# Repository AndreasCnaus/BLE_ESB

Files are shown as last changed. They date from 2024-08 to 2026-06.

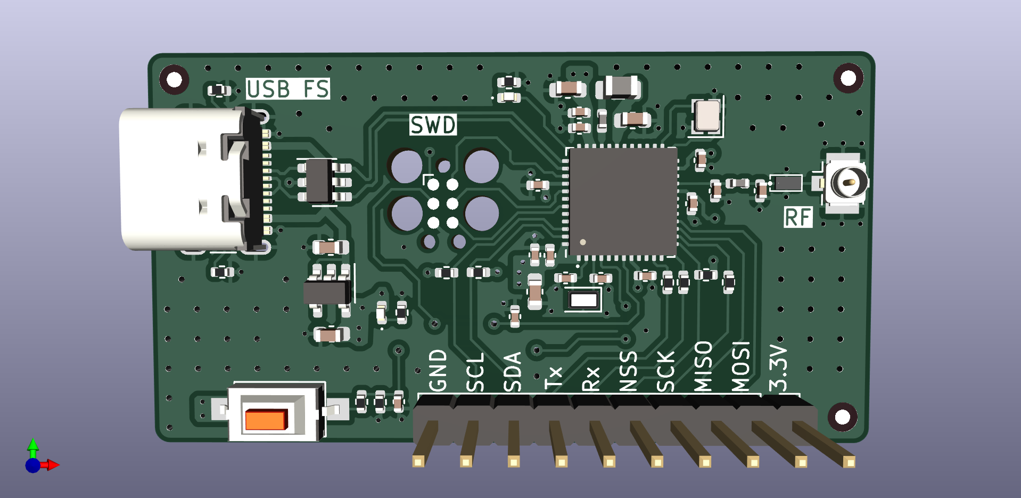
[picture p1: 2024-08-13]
hardware/docs/BluetoothPill.png

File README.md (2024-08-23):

# Hardware Setup
- Bluetooth Breakout Board (see also Hardware Section)
- Bosch BME280 Sensor
- RF-Antenna

BLE_ESB_Prototyp

# Verification with nRF-Connect
ble_es_data

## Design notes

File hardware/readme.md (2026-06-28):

# Bluetooth Breakout Board

USB Powered STM32WB55 based breakout board for wireless applications within 2.4GHz ISM-Band (e.g BLE). 

BluetoothPill

# Characteristics
Input Voltage-Range: &nbsp; 3.4V - 5.5V <br>
Output Voltage: &nbsp; 3.3V <br>
Crystals: &nbsp; HSE: 32MHz, LSE: 32.768kHz <br> 
MCU: &nbsp; STM32WB55CEU6 <br>
SMPS-Support: &nbsp;  for low power mode <br>
BOOT0/User-Button: &nbsp; boots from USB when pushed during power up <br>
LED's:  &nbsp; Power-Led (orange), User-Led (blue) <br>
Serial Wire Debug with Tag-Connec <br>

## Connectivity
USB-FS with 12Mb/s <br>
I2C1: &nbsp; (SDA, SCL) <br>
UART1: &nbsp; (Tx, Rx) <br>
SPI1: &nbsp; (NSS, SCK, MISO, MOSI) <br>
RF: &nbsp; 2.4GHz ISM-Band, BLE 5.4, IEEE 802.15.4 (Zigbee 3.0, Thread 1.3) <br>

# Links
STM32WB55-Datasheet: &nbsp; https://www.st.com/resource/en/datasheet/stm32wb55cc.pdf <br>

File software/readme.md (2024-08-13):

pinout_view

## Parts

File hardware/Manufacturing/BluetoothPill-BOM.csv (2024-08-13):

Designator | Quantity | Value | Footprint | Description | Manufacturer | Manufacturer Part Number | Distributor Link
C1, C2, C5, C8, C16 | 5 | 4u7 | Capacitor_SMD:C_0603_1608Metric | Unpolarized capacitor | KYOCERA AVX | KGM15CR51E475KT | https://www.mouser.de/ProductDetail/KYOCERA-AVX/KGM15CR51E475KT?qs=Jm2GQyTW%2FbixQyNI34FoPQ%3D%3D
C3, C4, C6, C7, C9, C10, C11, C12, C15, C17 | 10 | 100n | Capacitor_SMD:C_0402_1005Metric | Unpolarized capacitor | Wurth Elektronik | 885012205086 | https://www.mouser.de/ProductDetail/Wurth-Elektronik/885012205086?qs=amGC7iS6iy9PDKAAMqQhzg%3D%3D
C13, C14 | 2 | 10p | Capacitor_SMD:C_0402_1005Metric | Unpolarized capacitor | KEMET | C0402C100K8HACAUTO | https://www.mouser.de/ProductDetail/KEMET/C0402C100K8HACAUTO?qs=j%252B1pi9TdxUbSCidW22i%2FeQ%3D%3D
C18 | 1 | 0p8 | Capacitor_SMD:C_0402_1005Metric | Unpolarized capacitor | Murata Electronics | GRM1555C1HR80BA01D | https://www.mouser.de/ProductDetail/Murata-Electronics/GRM1555C1HR80BA01D?qs=e%252BE4OD6MgMezPYPintwvrA%3D%3D
C19 | 1 | 0p3 | Capacitor_SMD:C_0402_1005Metric | Unpolarized capacitor | Murata Electronics | GRM1555C1HR30WA01D | https://www.mouser.de/ProductDetail/Murata-Electronics/GRM1555C1HR30WA01D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
D1 | 1 | Green | LED_SMD:LED_0402_1005Metric | Light emitting diode | Lite-On | LTST-C281KGKT | https://www.mouser.de/ProductDetail/Lite-On/LTST-C281KGKT?qs=xb8aMrBSZRJ6%2FVAKgwiAkw%3D%3D
D2 | 1 | Blue | LED_SMD:LED_0402_1005Metric | Light emitting diode | Vishay Semiconductors | VLMB1500-GS08 | https://www.mouser.de/ProductDetail/Vishay-Semiconductors/VLMB1500-GS08?qs=2BArZ0I3Qlk9hauZMM5azA%3D%3D
FTL1 | 1 | DLF162500LT-5028A1 | custom:DLF162500LT-5028A1 | RF-Lowpass filter | TDK | DLF162500LT-5028A1 | https://www.mouser.de/ProductDetail/TDK/DLF162500LT-5028A1?qs=U%2FZX79kHR%2FlwIbAISCs3qA%3D%3D
J1 | 1 | USB_C_Receptacle_USB2.0 | Connector_USB:USB_C_Receptacle_GCT_USB4105-xx-A_16P_TopMnt_Horizontal | USB 2.0-only Type-C Receptacle connector | GCT | USB4105-GF-A | https://www.mouser.de/ProductDetail/GCT/USB4105-GF-A?qs=KUoIvG%2F9IlY%2FMLlBMpStpA%3D%3D
J4 | 1 | Conn_Coaxial | Connector_Coaxial:U.FL_Hirose_U.FL-R-SMT-1_Vertical | coaxial connector (BNC, SMA, SMB, SMC, Cinch/RCA, LEMO, ...) | Hirose Connector | U.FL-R-SMT(01) | https://www.mouser.de/ProductDetail/Hirose-Connector/U.FL-R-SMT01?qs=Ux3WWAnHpjDV3tCCbDi65g%3D%3D
L1 | 1 | 10n | Inductor_SMD:L_0402_1005Metric | Inductor | Murata Electronics | LQG15WZ10NJ02D | https://www.mouser.de/ProductDetail/Murata-Electronics/LQG15WZ10NJ02D?qs=60uY6ySkanT1eJ7IaeAl%2Fg%3D%3D
L2 | 1 | 10u | Inductor_SMD:L_0805_2012Metric | Inductor | Murata Electronics | LQM21FN100M70L | https://www.mouser.de/ProductDetail/Murata-Electronics/LQM21FN100M70L?qs=8M15sSGRUn%252BogwBrvQUwLA%3D%3D
L3 | 1 | 2n7 | Inductor_SMD:L_0402_1005Metric | Inductor | Murata Electronics | LQG15HS2N7S02D | https://www.mouser.de/ProductDetail/Murata-Electronics/LQG15HS2N7S02D?qs=ctz47l0uL1AKrLI74yO5Qw%3D%3D
R1, R2, R3, R6, R7, R12 | 6 | 220R | Resistor_SMD:R_0402_1005Metric | Resistor | YAGEO | AF0402JR-07220RL | https://www.mouser.de/ProductDetail/YAGEO/AF0402JR-07220RL?qs=Ghq3E7L6HNfV8BjGdjwaqw%3D%3D
R4, R5, R8, R9, R10, R11 | 6 | 5k1 | Resistor_SMD:R_0402_1005Metric | Resistor | Panasonic | ERJ-2RKF5101X | https://www.mouser.de/ProductDetail/Panasonic/ERJ-2RKF5101X?qs=YMBIwoNQYdXx9lAucePQAA%3D%3D
SW1 | 1 | SW_Push | Button_Switch_SMD:SW_SPST_CK_RS282G05A3 | Push button switch, generic, two pins | C&K | RS282G05A3SMRT | https://www.mouser.de/ProductDetail/CK/RS282G05A3SMRT?qs=Gufeu08L%2Fl2VU43xmeLp5Q%3D%3D
U1 | 1 | MIC5365-3.3YD5 | Package_TO_SOT_SMD:SOT-23-5 | 150mA Low-dropout Voltage Regulator, Vout 3.3V, Vin up to 5.5V, SOT-23-5 | Microchip Technology | MIC5365-3.3YD5-TR | https://www.mouser.de/ProductDetail/Microchip-Technology/MIC5365-3.3YD5-TR?qs=U6T8BxXiZAXzRinbbfZRrg%3D%3D
U2 | 1 | USBLC6-2SC6 | Package_TO_SOT_SMD:SOT-23-6 | Very low capacitance ESD protection diode, 2 data-line, SOT-23-6 | STMicroelectronics | USBLC6-2SC6 | https://www.mouser.de/ProductDetail/STMicroelectronics/USBLC6-2SC6?qs=po45yt2pPpu%2FhNIlwQdTlg%3D%3D
U3 | 1 | STM32WB55CEU6 | Package_DFN_QFN:QFN-48-1EP_7x7mm_P0.5mm_EP5.6x5.6mm | STMicroelectronics Arm Cortex-M4 MCU, 512KB flash, 256KB RAM, 64 MHz, 1.71-3.6V, 30 GPIO, UFQFPN48 | STMicroelectronics | STM32WB55CEU6 | https://www.mouser.de/ProductDetail/STMicroelectronics/STM32WB55CEU6
X1 | 1 | 32k768 | Crystal:Crystal_SMD_2012-2Pin_2.0x1.2mm | Two pin crystal | NDK | NX2012SA-32.768K-STD-MUB-1 | https://www.mouser.de/ProductDetail/NDK/NX2012SA-32.768K-STD-MUB-1?qs=55YtniHzbhA%252B6%2Fl1MwFZaQ%3D%3D
X2 | 1 | 32M | Crystal:Crystal_SMD_2016-4Pin_2.0x1.6mm | Four pin crystal, GND on pins 2 and 4 | NDK | NX2016SA-32M-EXS00A-CS06465 | https://www.mouser.de/ProductDetail/NDK/NX2016SA-32M-EXS00A-CS06465?qs=w%2Fv1CP2dgqr82b0JjRnv4A%3D%3D

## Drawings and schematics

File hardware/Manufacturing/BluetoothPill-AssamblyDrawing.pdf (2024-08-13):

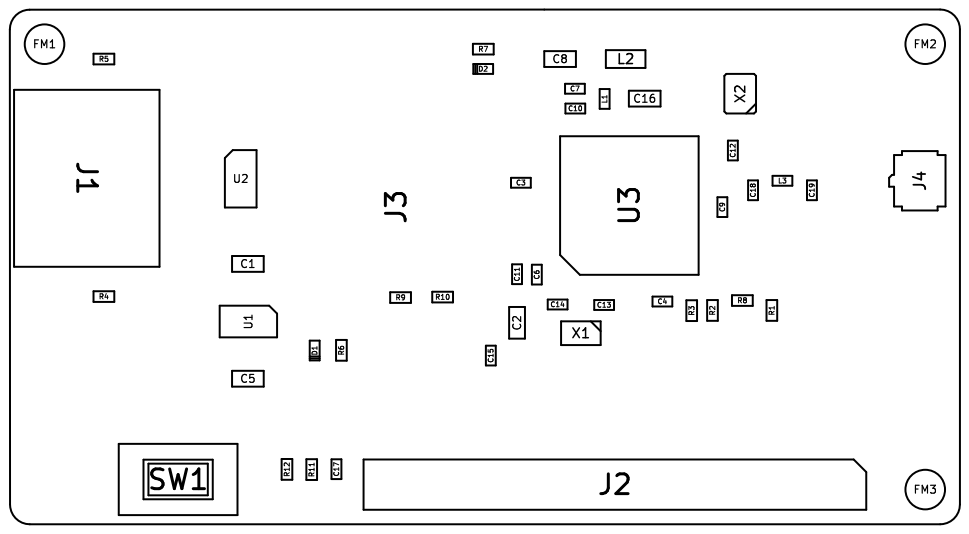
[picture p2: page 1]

Id: 1/1 Title: File: BluetoothPill.kicad_pcb Sheet:

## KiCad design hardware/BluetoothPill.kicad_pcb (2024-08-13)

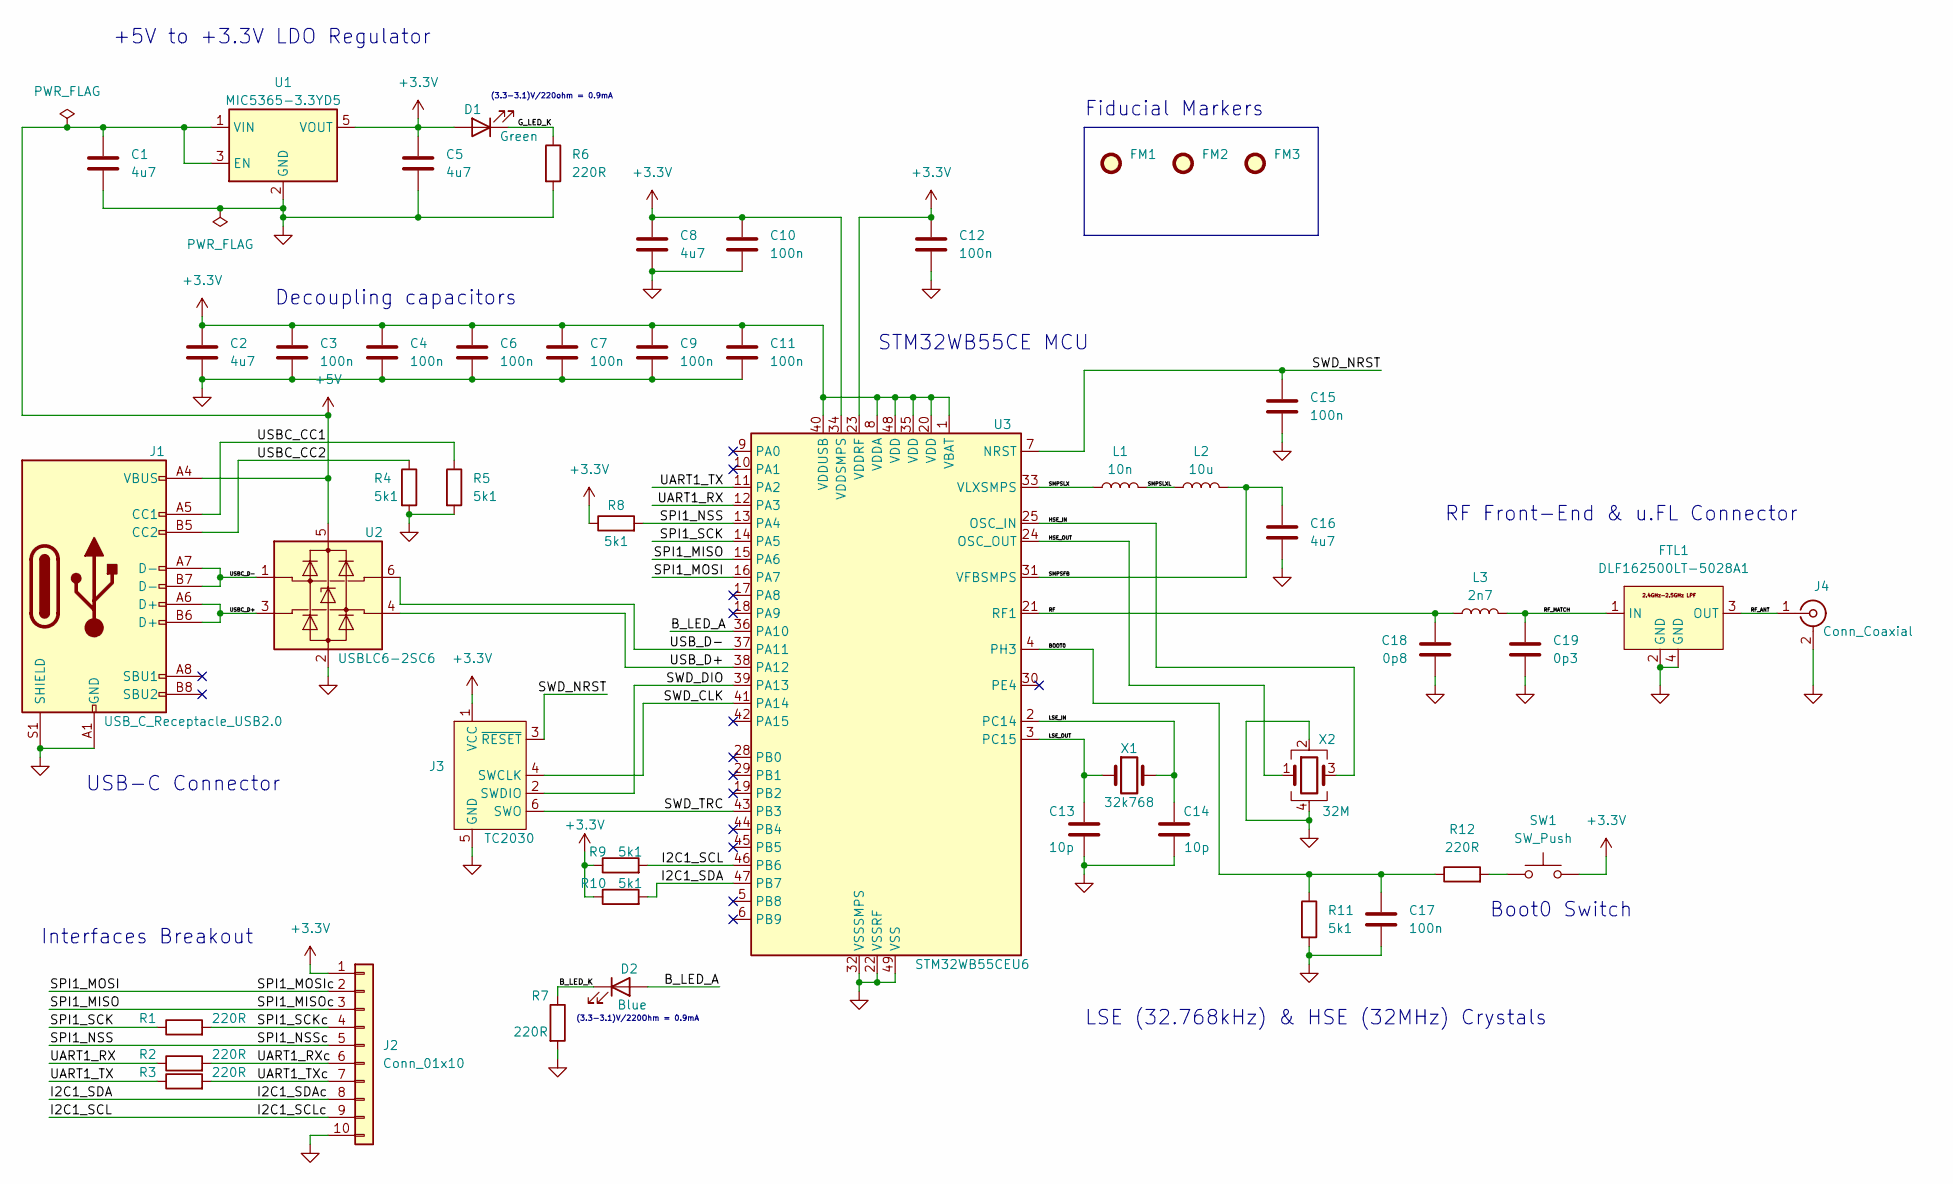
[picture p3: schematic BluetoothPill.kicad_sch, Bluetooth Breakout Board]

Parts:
C1, C2, C5, C8, C16: 4u7; C_0603_1608Metric; Manufacturer Part Numb KGM15CR51E475KT
C3, C4, C6, C7, C9, C10, C11, C12, C15, C17: 100n; C_0402_1005Metric; Manufacturer Part Numb 885012205086
C13, C14: 10p; C_0402_1005Metric; Manufacturer Part Numb C0402C100K8HACAUTO
C18: 0p8; C_0402_1005Metric; Manufacturer Part Numb GRM1555C1HR80BA01D
C19: 0p3; C_0402_1005Metric; Manufacturer Part Numb GRM1555C1HR30WA01D
D1: Green; LED_0402_1005Metric; Manufacturer Part Numb LTST-C281KGKT
D2: Blue; LED_0402_1005Metric; Manufacturer Part Numb VLMB1500-GS08
FM1, FM2, FM3: Fiducial; Fiducial_1mm_Mask2mm
FTL1: DLF162500LT-5028A1; Manufacturer Part Numb DLF162500LT-5028A1
J1: USB_C_Receptacle_USB2.0; USB_C_Receptacle_GCT_USB4105-xx-A_16P_TopMnt_Horizontal; Manufacturer Part Numb USB4105-GF-A
J2: Conn_01x10; PinHeader_1x10_P2.54mm_Vertical
J3: TC2030; Tag-Connect_TC2030-IDC-FP_2x03_P1.27mm_Vertical
J4: Conn_Coaxial; U.FL_Hirose_U.FL-R-SMT-1_Vertical; Manufacturer Part Numb U.FL-R-SMT(01)
L1: 10n; L_0402_1005Metric; Manufacturer Part Numb LQG15WZ10NJ02D
L2: 10u; L_0805_2012Metric; Manufacturer Part Numb LQM21FN100M70L
L3: 2n7; L_0402_1005Metric; Manufacturer Part Numb LQG15HS2N7S02D
R1, R2, R3, R6, R7, R12: 220R; R_0402_1005Metric; Manufacturer Part Numb AF0402JR-07220RL
R4, R5, R8, R9, R10, R11: 5k1; R_0402_1005Metric; Manufacturer Part Numb ERJ-2RKF5101X
SW1: SW_Push; SW_SPST_CK_RS282G05A3; Manufacturer Part Numb RS282G05A3SMRT
U1: MIC5365-3.3YD5; SOT-23-5; Manufacturer Part Numb MIC5365-3.3YD5-TR
U2: USBLC6-2SC6; SOT-23-6; Manufacturer Part Numb USBLC6-2SC6
U3: STM32WB55CEU6; QFN-48-1EP_7x7mm_P0.5mm_EP5.6x5.6mm; Manufacturer Part Numb STM32WB55CEU6
X1: 32k768; Crystal_SMD_2012-2Pin_2.0x1.2mm; Manufacturer Part Numb NX2012SA-32.768K-STD-MUB-1
X2: 32M; Crystal_SMD_2016-4Pin_2.0x1.6mm; Manufacturer Part Numb NX2016SA-32M-EXS00A-CS06465

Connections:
+3.3V: C2.1, C3.1, C4.1, C5.1, C6.1, C7.1, C8.1, C9.1, C10.1, C11.1, C12.1, D1.2 (A), J2.1, J3.1 (VCC), R8.1, R9.1, R10.1, SW1.2, U1.5 (VOUT), U3.1 (VBAT), U3.8 (VDDA), U3.20 (VDD), U3.23 (VDDRF), U3.34 (VDDSMPS), U3.35 (VDD), U3.40 (VDDUSB), U3.48 (VDD)
+5V: C1.1, J1.A4 (VBUS), J1.A9 (VBUS), J1.B4 (VBUS), J1.B9 (VBUS), U1.1 (VIN), U1.3 (EN), U2.5 (VBUS)
/BOOT0: C17.1, R11.1, R12.1, U3.4 (PH3)
/B_LED_A: D2.2 (A), U3.36 (PA10)
/B_LED_K: D2.1 (K), R7.1
/G_LED_K: D1.1 (K), R6.1
/HSE_IN: U3.25 (OSC_IN), X2.3
/HSE_OUT: U3.24 (OSC_OUT), X2.1
/I2C1_SCL: J2.9, R9.2, U3.46 (PB6)
/I2C1_SDA: J2.8, R10.2, U3.47 (PB7)
/LSE_IN: C14.1, U3.2 (PC14), X1.2
/LSE_OUT: C13.1, U3.3 (PC15), X1.1
/RF: C18.1, L3.1, U3.21 (RF1)
/RF_ANT: FTL1.3 (OUT), J4.1 (In)
/RF_MATCH: C19.1, FTL1.1 (IN), L3.2
/SMPSFB: C16.1, L2.2, U3.31 (VFBSMPS)
/SMPSLX: L1.1, U3.33 (VLXSMPS)
/SMPSLXL: L1.2, L2.1
/SPI1_MISO: J2.3, U3.15 (PA6)
/SPI1_MOSI: J2.2, U3.16 (PA7)
/SPI1_NSS: J2.5, R8.2, U3.13 (PA4)
/SPI1_SCK: R1.1, U3.14 (PA5)
/SPI1_SCKc: J2.4, R1.2
/SWD_CLK: J3.4 (SWCLK), U3.41 (PA14)
/SWD_DIO: J3.2 (SWDIO), U3.39 (PA13)
/SWD_NRST: C15.1, J3.3 (~RESET), U3.7 (NRST)
/SWD_TRC: J3.6 (SWO), U3.43 (PB3)
/UART1_RX: R2.1, U3.12 (PA3)
/UART1_RXc: J2.6, R2.2
/UART1_TX: R3.1, U3.11 (PA2)
/UART1_TXc: J2.7, R3.2
/USBC_CC1: J1.A5 (CC1), R5.1
/USBC_CC2: J1.B5 (CC2), R4.1
/USBC_D+: J1.A6 (D+), J1.B6 (D+), U2.3 (I/O1)
/USBC_D-: J1.A7 (D-), J1.B7 (D-), U2.1 (I/O1)
/USB_D+: U2.4 (I/O2), U3.38 (PA12)
/USB_D-: U2.6 (I/O2), U3.37 (PA11)
GND: C1.2, C2.2, C3.2, C4.2, C5.2, C6.2, C7.2, C8.2, C9.2, C10.2, C11.2, C12.2, C13.2, C14.2, C15.2, C16.2, C17.2, C18.2, C19.2, FTL1.2 (GND), FTL1.4 (GND), J1.A1 (GND), J1.A12 (GND), J1.B1 (GND), J1.B12 (GND), J1.S1 (SHIELD), J2.10, J3.5 (GND), J4.2 (Ext), R4.2, R5.2, R6.2, R7.2, R11.2, U1.2 (GND), U2.2 (GND), U3.22 (VSSRF), U3.32 (VSSSMPS), U3.49 (VSS), X2.2, X2.4
unnamed: R12.2, SW1.1

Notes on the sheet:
Fiducial Markers
USB-C Connector
RF Front-End & u.FL Connector
+5V to +3.3V LDO Regulator
(3.3-3.1)V/220Ohm = 0.9mA
LSE (32.768kHz) & HSE (32MHz) Crystals
Interfaces Breakout
Decoupling capacitors
Boot0 Switch
(3.3-3.1)V/220ohm = 0.9mA
STM32WB55CE MCU

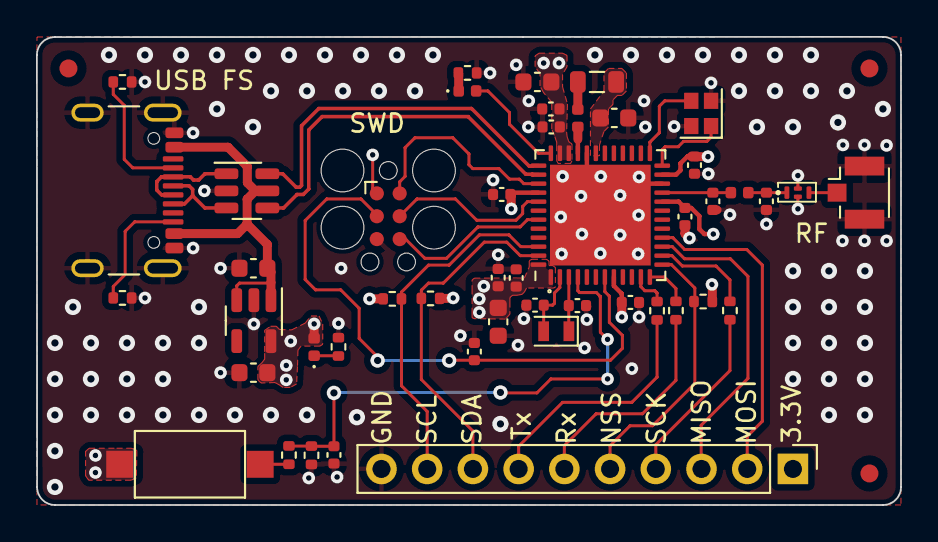
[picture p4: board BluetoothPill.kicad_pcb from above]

Board: 4 copper layers, 48.0 x 26.0 mm, 50 parts (0 on the bottom side), 39 nets.

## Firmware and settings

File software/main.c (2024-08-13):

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
/* Includes ------------------------------------------------------------------*/
#include "main.h"
#include "usb_device.h"

/* USER CODE BEGIN Includes */
#include <stdio.h>

#include "usbd_cdc_if.h"
#include "common_blesvc.h"
#include "custom_stm.h"
#include "BME280.h"
#include <stdlib.h>

/* USER CODE END Includes */

/* USER CODE BEGIN PTD */
uint8_t tim16_flag = 0;

/* USER CODE END PTD */

I2C_HandleTypeDef hi2c1;

IPCC_HandleTypeDef hipcc;

RTC_HandleTypeDef hrtc;

TIM_HandleTypeDef htim16;

/* USER CODE BEGIN PV */
BME280 bme280;
uint8_t tim16_cnt = 0;

/* USER CODE END PV */

void SystemClock_Config(void);
void PeriphCommonClock_Config(void);
static void MX_GPIO_Init(void);
static void MX_IPCC_Init(void);
static void MX_RTC_Init(void);
static void MX_TIM16_Init(void);
static void MX_I2C1_Init(void);
static void MX_RF_Init(void);
/**
  * @brief  The application entry point.
  * @retval int
  */
int main(void)
{

  /* MCU Configuration--------------------------------------------------------*/

  /* Reset of all peripherals, Initializes the Flash interface and the Systick. */
  HAL_Init();
  /* Config code for STM32_WPAN (HSE Tuning must be done before system clock configuration) */
  MX_APPE_Config();

  /* Configure the system clock */
  SystemClock_Config();

  /* Configure the peripherals common clocks */
  PeriphCommonClock_Config();

  /* IPCC initialisation */
  MX_IPCC_Init();

  /* Initialize all configured peripherals */
  MX_GPIO_Init();
  MX_RTC_Init();
  MX_TIM16_Init();
  MX_I2C1_Init();
  MX_USB_Device_Init();
  MX_RF_Init();
  /* USER CODE BEGIN 2 */
  BME280_cmd_res cmd_res = BME280_init(&bme280, &hi2c1);
  if (cmd_res != BME280_CMD_OK) {
	  HAL_GPIO_WritePin(GPIOA, GPIO_PIN_10, GPIO_PIN_SET);	// indicate error with LED on PA10
  }

  /* USER CODE END 2 */

  /* Init code for STM32_WPAN */
  MX_APPE_Init();

  /* Infinite loop */
  /* USER CODE BEGIN WHILE */
  HAL_TIM_Base_Start_IT(&htim16);

  while (1)
  {
	  if (tim16_flag){

		  BME280_cmd_res cmd_res = BME280_read_env_data(&bme280);
		  if (cmd_res != BME280_CMD_OK) {
			  HAL_GPIO_WritePin(GPIOA, GPIO_PIN_10, GPIO_PIN_SET);	// indicate error with LED on PA10
		  }

		  // convert measurement data to the appropriate units for nRF-Connect Application
		  BME280_U32_t hum_prh = (float)bme280.H/kH * 100.0;	// relative humidity in Percent
		  BME280_U32_t pres_pa=  bme280.P/kP;	//in Pascal

		  Custom_STM_App_Update_Char(CUSTOM_STM_TEMPERATURE, (uint8_t *)&bme280.T);
		  Custom_STM_App_Update_Char(CUSTOM_STM_HUMIDITY, (uint8_t *)&hum_prh);
		  Custom_STM_App_Update_Char(CUSTOM_STM_PRESSURE, (uint8_t *)&pres_pa);

		  tim16_flag = 0;
	  }
    /* USER CODE END WHILE */
    MX_APPE_Process();

    /* USER CODE BEGIN 3 */
  }
  /* USER CODE END 3 */
}

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
/* USER CODE BEGIN 4 */
void HAL_TIM_PeriodElapsedCallback(TIM_HandleTypeDef *htim)
{
	// Check which version of the timer triggered this callback
	if (htim == &htim16 )
	{
		if (tim16_cnt >= 5)	// for IPPC sync.
			tim16_flag = 1;
		else
			tim16_cnt++;
	}
}

/* USER CODE END 4 */
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


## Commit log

2024-08-13 Add initial hardware design for KiCAD 7.0
    Following files were added:
    Schematic
    PCB-Layout with 3D-Models
    Manufactoring files for PCB-Way
    [BluetoothPill-BOM.csv, BluetoothPill.kicad_pcb, BluetoothPill.kicad_sch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]
2024-08-13 Initial add of BLE-Software section
    Consists of:
    BME280 I2C-HAL Driver
    Main file

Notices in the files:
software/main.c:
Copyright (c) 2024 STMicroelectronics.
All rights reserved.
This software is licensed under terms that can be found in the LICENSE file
